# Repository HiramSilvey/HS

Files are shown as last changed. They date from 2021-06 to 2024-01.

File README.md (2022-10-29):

# HS

A highly customizable game controller with a fully analog arcade-style joystick.

To see it in action, check out this [demo](https://www.youtube.com/watch?v=5yk12DYtFRA)!

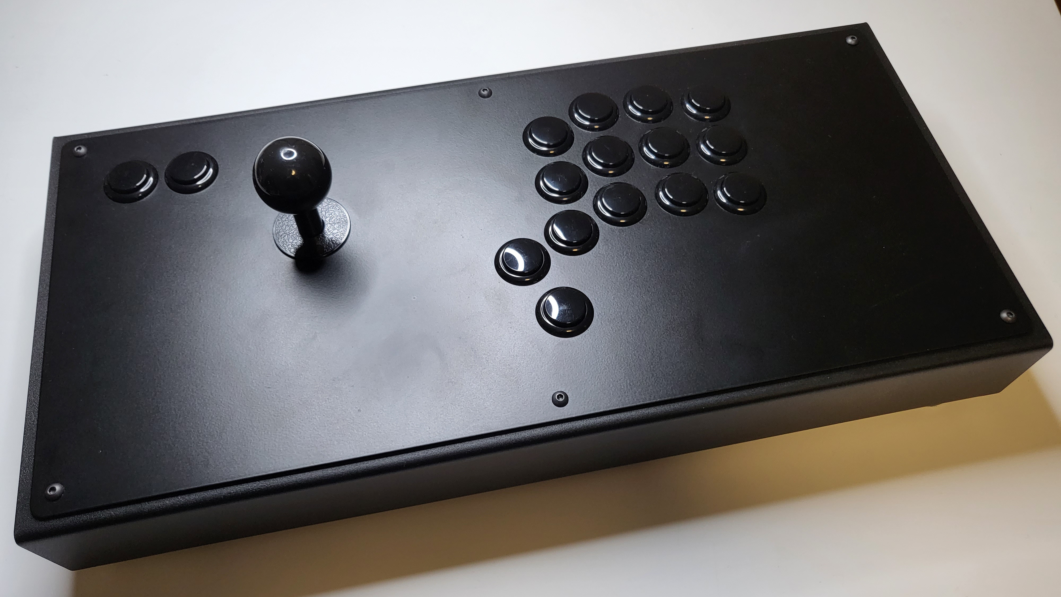
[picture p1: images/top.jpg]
HS-top-side

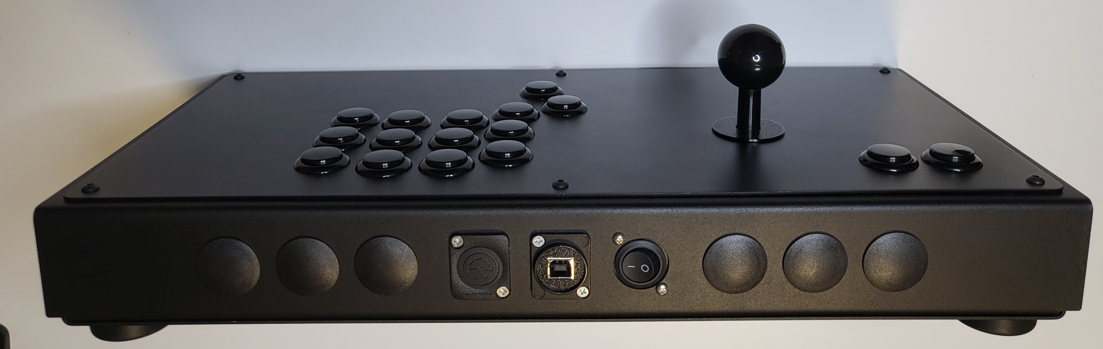
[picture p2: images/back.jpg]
HS-back-side


## Key features
* Fully analog joystick
* Works on PC and Switch, with more platforms planned
* Supports up to 12 custom button layout profiles per platform
* In-depth joystick calibration software to ensure maximum analog precision

## Profile features
* All buttons are remappable
* Buttons can be mapped to either digital or analog outputs
* Supports an optional second button layout, which becomes active while the MOD button is held down
* Supports digital joystick emulation with a custom activation threshold

## Specs
* 14", 16", or 18" standard AllFightSticks case
* 11-14 right-hand buttons, depending on the panel style chosen
* 2 left-hand buttons (recommended), either on the panel top or the back
* 1 on/off rocker switch, to specify platform (PC or Switch)
* 1 USB-C 2.0 port
* PJRC Teensy 4.0 microcontroller
* Contactless joystick via the Infineon TLV493D-A1B6 3D hall effect sensor

## TO DO
1. Write up and publish build guide
2. Rewrite the configurator frontend to support Windows & MacOS (currently Linux only)
3. Support native GameCube output

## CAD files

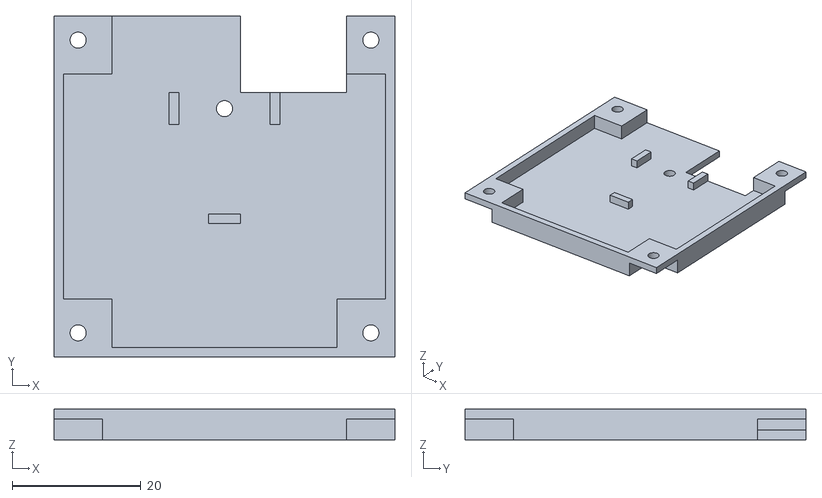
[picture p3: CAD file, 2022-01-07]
hardware/joystick/out/sensor_harness_01_spacing.stl
53.0 x 53.0 x 4.75

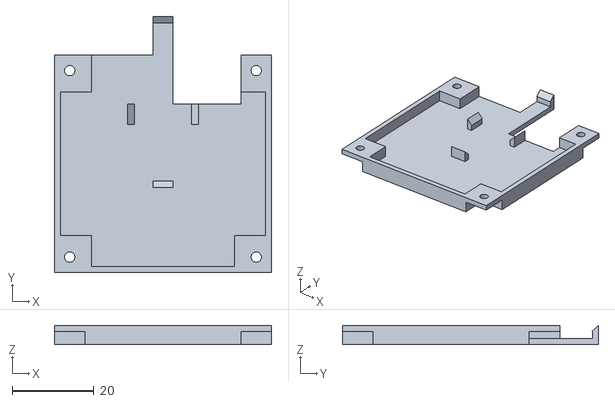
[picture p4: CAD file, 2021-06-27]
hardware/joystick/out/sensor_harness_01_spacing_01_lip.stl
53.0 x 62.5 x 4.75

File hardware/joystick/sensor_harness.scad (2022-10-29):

// All units are in mm.

min_thickness=1.5;
depth=min_thickness;
m3_dia=2.5;

width=53;
length=width;
edge_to_hole=3.75;
inner_offset=edge_to_hole*2;
inner_width=width-inner_offset*2;
inner_depth=4.75;

cutout_depth=inner_depth-min_thickness;
cutout_depth_offset=depth-cutout_depth;

board_spacing=0.1;  // Calibrated for the Prusa i3 FDM printer.
board_width=14+board_spacing;
board_height=38.5+board_spacing;
board_width_offset=(width-board_width)/2;
board_height_edge_to_sensor_center=4.35+(board_spacing/2);
board_height_offset=(width/2)-board_height_edge_to_sensor_center;
board_height_edge_to_hole_center=16.1+(board_spacing/2);
board_hole_offset=board_height_offset+board_height_edge_to_hole_center;
rail_length=6;
notch_width=(board_width-rail_length)/2;

module hole(x, y, d, dia) {
     translate([x, y, d]) cylinder(h=4.75, d=dia, center=false, $fn=100);
}

module core() {
     // Outer platform
     difference () {
	  cube([width, length, depth]);
	  hole(edge_to_hole, edge_to_hole, 0, m3_dia);
	  hole(width-edge_to_hole, edge_to_hole, 0, m3_dia);
	  hole(edge_to_hole, width-edge_to_hole, 0, m3_dia);
	  hole(width-edge_to_hole, width-edge_to_hole, 0, m3_dia);
     }
     // Solid inner platform
     translate([inner_offset, 0, depth-inner_depth])
	  cube([inner_width, width, inner_depth]);
     translate([0, inner_offset, depth-inner_depth])
	  cube([width, inner_width, inner_depth]);
}

module board() {
    // Header cutout
    translate([width/2+rail_length/2, board_hole_offset+rail_length/2,
	      depth-inner_depth]) cube([width/2-rail_length/2-edge_to_hole*2,
				       width-board_hole_offset+rail_length/2,
				       inner_depth]);
    // Board cutout
    translate([board_width_offset, board_height_offset, cutout_depth_offset])
	 cube([board_width, board_height, inner_depth]);
    // Board notches cutout
    translate([board_width_offset, board_height_offset-min_thickness, cutout_depth_offset])
	 cube([notch_width, min_thickness, inner_depth]);
    translate([board_width_offset+board_width-notch_width, board_height_offset-min_thickness, cutout_depth_offset])
	 cube([notch_width, min_thickness, inner_depth]);
}

module platform_extension() {
    translate([width/2-board_width/2-min_thickness, width, depth-inner_depth]) cube([board_width/2+rail_length/2+min_thickness, board_height_offset+board_height-width+min_thickness, min_thickness]);
    translate([width/2-rail_length/2, board_height_offset+board_height,
    cutout_depth_offset]) cube([rail_length, min_thickness, cutout_depth]);
    translate([width/2-board_width/2-min_thickness, width, cutout_depth_offset]) cube([min_thickness, board_height_offset+board_height-width+min_thickness, cutout_depth]);
}

difference () {
    core();
    board();
}

platform_extension();

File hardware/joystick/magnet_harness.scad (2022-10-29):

// All units are in mm.

spacing=0.1;  // Calibrated for the Prusa i3 FDM printer.

min_thickness=1;
shaft_height=2;
shaft_dia=6.85+spacing;
magnet_height=3.175;  // 0.125"
magnet_dia=19.05+spacing;  // 0.750"
outer_dia=magnet_dia+(2*min_thickness);

$fn=360;

difference() {
  body();
  magnet();
  shaft();
}

module body() {
  cylinder(h=magnet_height+shaft_height, d1=outer_dia, d2=outer_dia);
}

module magnet() {
  translate([0,0,0]) {
    cylinder(h=magnet_height, d1=magnet_dia, d2=magnet_dia);
  }
}

module shaft() {
  translate([0,0,magnet_height]) {
    cylinder(h=shaft_height, d1=shaft_dia, d2=shaft_dia);
  }
}

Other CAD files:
hardware/joystick/src/magnet_harness.scad

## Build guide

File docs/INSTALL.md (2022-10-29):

# Required tools
1. Soldering iron + solder
2. 22 gauge wire strippers
3. Standard phillips head screwdrivers
4. 3/32" allen wrench

# Parts
| Link | Quantity  |
|:---|:---|
| [Teensy 4.0](https://www.digikey.com/en/products/detail/sparkfun-electronics/DEV-15583/10384551) | 1 |
| [TLV493D-A1B6 magnetic sensor board](https://www.digikey.com/en/products/detail/infineon-technologies/S2GO3DSENSETLV493DTOBO1/9808564) | 1 |
| [Magnet](https://www.digikey.com/en/products/detail/radial-magnets-inc/8013/555325) | 1 |
| [1x5 male pin header](https://www.digikey.com/en/products/detail/sullins-connector-solutions/PBC05SAAN/859626) | 1 |
| [1x14 male pin header](https://www.digikey.com/en/products/detail/sullins-connector-solutions/PBC14SAAN/859635) | 2 |
| [1x3 screw terminal header](https://www.digikey.com/en/products/detail/on-shore-technology-inc/OSTVN03A150/1588863) | 1 |
| [1x4 screw terminal header](https://www.digikey.com/en/products/detail/on-shore-technology-inc/OSTVN04A150/1588864) | 3 |
| [1x10 screw terminal header](https://www.digikey.com/en/products/detail/on-shore-technology-inc/OSTVN10A150/1588870) | 1 |
| [1x12 screw terminal header](https://www.digikey.com/en/products/detail/on-shore-technology-inc/OSTVN12A150/1588872) | 2 |
| [40mm brass spacer](https://www.digikey.com/en/products/detail/w%C3%BCrth-elektronik/970400324/9488593) | 4 |
| [M3 machine screw](https://www.digikey.com/en/products/detail/keystone-electronics/9191-3/4499484) | 4 |
| [Teensy breakout board](https://www.tindie.com/products/raster/teensy-breakout-board-v16/) | 1 |
| [Sanwa JLF-TP-8YT joystick](https://focusattack.com/sanwa-jlf-tp-8yt-joystick/) | 1 |
| [Seimitsu black LB-35 balltop](https://focusattack.com/seimitsu-solid-color-black-lb-35-balltop/) | 1 |
| [Short Sanwa JLF joystick shaft](https://focusattack.com/short-sanwa-jlf-joystick-shaft/) | 1 |
| [Sanwa GT-8X square restrictor gate](https://focusattack.com/sanwa-gt-8x-square-restrictor-gate/) | 1 |
| [GTN-R square mod type I restrictor gate insert](https://focusattack.com/gtn-r-square-mod-type-i-restrictor-gate-insert/) | 1 |
| [Sanwa JLF blue spring (1.5, 1.5 tension load)](https://focusattack.com/sanwa-jlf-blue-spring-1-5-1-5-tension-load/) | 1 |
| [Sanwa JLF P-R actuator](https://focusattack.com/sanwa-jlf-p-r-actuator/) | 1 |
| [Solo Sanwa JLF dustwasher](https://focusattack.com/solo-sanwa-jlf-dustwasher-fits-sanwa-jlf-without-shaft-cover-set-of-2/) | 1 |
| [Sanwa JLF-SS-kit](https://focusattack.com/sanwa-jlf-ss-kit-set-of-4/) | 1 |
| [USB C jack to USB A jack round panel mount adapter](https://focusattack.com/usb-c-jack-to-usb-a-jack-round-panel-mount-adapter/) | 1 |
| [16pc 22 AWG wire with .110 quick disconnect](https://focusattack.com/16pc-22-awg-wire-with-110-quick-disconnect/) | 1 |
| [16pc 22 AWG wire with .187 quick disconnect](https://focusattack.com/16pc-22-awg-wire-with-187-quick-disconnect/) | 1 |
| [30 connection 22 AWG .110" ground daisy chain wire](https://focusattack.com/30-connection-22-awg-110-ground-daisy-chain-wire/) | 1 |
| [3mm hole low profile adhesize PCB feet (set of 4)](https://focusattack.com/3mm-hole-low-profile-adhesive-pcb-feet-set-of-4/) | 1 |
| [24mm Pushbutton](https://focusattack.com/controls/pushbutton/by-hole-diameter/24mm/) | 12/16[^1] |
| [Neutrik DBA-BL blank plate](https://focusattack.com/neutrik-dba-bl-blank-plate/) | 1 |
| [Hole plug](https://allfightsticks.com/products/screw-in-hole-plugs) | 4-6[^2] |
| AllFightSticks enclosure ([14"](https://allfightsticks.com/collections/14-enclosures/products/14-semi-modular-body), [16"](https://allfightsticks.com/collections/16-enclosures/products/16-bodies), [18"](https://allfightsticks.com/collections/18-enclosures/products/18-standard-bodies))[^3] | 1 |
| [10 foot male A-C USB 2.0 cable](https://www.amazon.com/gp/product/B01D3095RW) | 1 |
| [Right angle micro USB to USB 2.0 cable](https://www.amazon.com/gp/product/B01LYYT3N3) | 1 |
| [Laser cut panel](/hardware/panel/README.md) | 1 |
| [3D printed joystick harnesses](/hardware/joystick/README.md) | 1 ea. |

[^1]: 12 pushbuttons if using the CORE panel layout; 16 pushbuttons if using the FULL panel layout.
[^2]: 6 hole plugs minus the number of extra buttons on the panel.
[^3]: Include a joystick mounting plate. Order without a button panel.

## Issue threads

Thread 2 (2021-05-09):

Clean up joystick calibration code and merge it into the main binary

HiramSilvey, 2021-05-09:

HiramSilvey, 2021-07-11:
Refactor calibration code to use full circle motions (easier to do) where only the largest and smallest values are kept (rather than averaging values). Then, do some manual testing to determine how close to those absolute minimums and maximums standard joystick movements get. From there, determine a threshold (e.g. 95%) which should be applied to the minimum and maximum values to obtain tighter bounds which allow all values of the joystick to realistically be reached in standard use.

Additionally add supporting code to the configurator client which sends and receives calibration serial data. This will enable users to move completely off of the Arduino IDE except for code updates (which will be tackled separately in the future).

Closed 2021-07-17.

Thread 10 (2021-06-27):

Add support for outputting to Nintendo Gamecube

HiramSilvey, 2021-06-27:
Arduino support for this is here: https://github.com/NicoHood/Nintendo
In order to support Teensy 4.0+, the protocol needs to be re-written since the NicoHood library is written specifically for the AVR cpu architecture. Since the Teensy is so much faster than the Arduino, though, it may be possible to implement the protocol using bit-banging rather than inserting the exact number of NOP instructions.

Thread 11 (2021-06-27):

Add support for outputting to N64

HiramSilvey, 2021-06-27:
Arduino support for this is here: https://github.com/NicoHood/Nintendo
In order to support Teensy 4.0+, the protocol needs to be re-written since the NicoHood library is written specifically for the AVR cpu architecture. Since the Teensy is so much faster than the Arduino, though, it may be possible to implement the protocol using bit-banging rather than inserting the exact number of NOP instructions.

HiramSilvey, 2021-06-30:
Investigate forking the controller implementation in https://github.com/Ryzee119/usb64.

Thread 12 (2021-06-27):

Add detailed documentation

HiramSilvey, 2021-06-27:
Document:
* The purpose of the controller
* The design principles of the controller
* How to build
** How to get the panel laser cut
* How to run the configurator
* How to run the calibration code
* How to use the controller

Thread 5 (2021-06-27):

Widen panel button holes to better fit 24mm Sanwa buttons

HiramSilvey, 2021-06-27:
The buttons do currently fit in the holes, but it's snug enough that inserting and removing them is difficult and can strip some of their side wall plastic off.

HiramSilvey, 2021-07-25:
This might be OK. Holes are 24.3mm currently, which is the desired width according to measurements I've made on commercial panels. I will re-open this if it feels too tight in a second build.

Closed 2021-07-25.

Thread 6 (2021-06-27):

Investigate Seimitsu LS40 joystick as a possible alternative

HiramSilvey, 2021-06-27:
Some fightstick users prefer the feel and tension options of the Seimitsu LS40 over the Sanwa JLF. Investigate what it would take to support this joystick and experiment with it, in case users are interested.

HiramSilvey, 2022-03-05:
Ordered LS-32 and LS-40 for experimentation.

HiramSilvey, 2022-03-26:
"ls-40" branch contains changes I've been playing around with.

Yesterday I got a working ls-40 prototype.
Pros:
1. Extremely stable sensor readings. No jitter whatsoever.
2. Shorter throw.
3. Less wiggling in neutral position.
4. Less snapback when releasing the joystick to neutral position.
Cons:
1. Rotating the joystick still affects the sensor readings more than I'd like. This doesn't appear to be worse than the JLF, though. To combat this, I'm going to try using the Seimitsu Nobi lever next, which uses the same bottom plates as the ls-40. The Nobi is unique because its joystick shaft cannot rotate.

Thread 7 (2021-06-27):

Experiment moving lowest thumb button to reduce strain

HiramSilvey, 2021-06-27:
Currently the lowest thumb button is pretty far from the highest thumb button. This introduces a fairly significant finger travel distance when moving from thumb top to thumb bottom. That affects both the speed at which the button can be pressed as well as the strain introduced on the thumb.

Closed 2021-07-25.

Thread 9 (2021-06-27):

Add support for outputting to Nintendo Switch

HiramSilvey, 2021-06-27:

HiramSilvey, 2021-06-28:
Try using https://github.com/gdsports/NSGadget_Teensy/blob/master/hardware/teensy/avr/cores/teensy4/usb_nsgamepad.h

HiramSilvey, 2021-06-29:
Example: https://github.com/gdsports/NSGadget_Teensy/blob/master/examples/NSGamepad/NSGamepad.ino

HiramSilvey, 2021-07-06:
See https://github.com/HiramSilvey/HS/commit/f24bbb9ad9f6cdd905fb99b6a781aad39aac6bb8 and previous few commits for details on how this was done.

Closed 2021-07-06.

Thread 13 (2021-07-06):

Dynamically set USB type based on hardware switch

HiramSilvey, 2021-07-06:
See https://forum.pjrc.com/threads/67639-Is-it-possible-to-have-a-dynamic-USB-VID-PID for more information.

Closed 2021-07-11.

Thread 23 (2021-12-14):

Verify profile creation and flashing works on Windows.

HiramSilvey, 2021-12-14:

HiramSilvey, 2022-02-26:
Communication with the controller works as expected, but the UI freezes and is rendered unusable. This might be a bug in druid, or may be an issue with my implementation.

I'm considering rewriting the UI in something like electron and calling into my rust functions from it for controller communication. Is that feasible? More research to be done.

HiramSilvey, 2022-02-27:
After some research, rewriting the UI using electron, node.js, and neon (https://github.com/neon-bindings/neon) seems pretty straightforward and should be very reliable across mac, linux, and windows.

I will move forward with this approach and convert the current druid implementation. This also seems like a good time to revamp the UI to include button layouts as well, so I'll need to do some UI mocking before really diving in.

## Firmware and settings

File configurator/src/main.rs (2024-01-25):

// Copyright 2024 Hiram Silvey

use anyhow::{anyhow, Result};
use configurator::encoder;
use configurator::profiles;
use crossbeam_channel::{unbounded, Receiver, Sender};
use druid::kurbo::{Circle, Line};
use druid::piet::StrokeStyle;
use druid::widget::prelude::*;
use druid::widget::{Button, Flex, Label, Painter};
use druid::{
    theme, AppLauncher, Color, Data, ExtEventSink, Lens, PlatformError, Point, Rect, RenderContext,
    Selector, Target, Widget, WidgetExt, WindowDesc,
};
use serialport::SerialPort;
use std::path::Path;
use std::thread;
use std::time::{Duration, Instant};

const MAX_EEPROM_BYTES: usize = 1064;
const JOYSTICK_CURSOR_RADIUS: f64 = 3.;
const JOYSTICK_BOX_LENGTH: f64 = 400.;
const SET_CURSOR: Selector<Point> = Selector::new("hs.set-cursor");
const SET_DEFAULT_BOUNDS: Selector<Bounds> = Selector::new("hs.set-default-bounds");

#[derive(Clone, Copy)]
enum Command {
    FetchStoredBounds,
    FetchJoystickCoords,
    CalibrateJoystick,
    SaveCalibration,
    StoreProfiles,
}

#[derive(Clone, Copy, Data, Lens)]
struct Bounds {
    center: Point,
    range: f64,
    angle_ticks: i16,
}

impl Bounds {
    pub fn new() -> Bounds {
        Bounds {
            center: Point::new(0.0, 0.0),
            range: 0.0,
            angle_ticks: 0,
        }
    }

    pub fn from_parts(center_x: f64, center_y: f64, range: f64, angle_ticks: i16) -> Bounds {
        Bounds {
            center: Point::new(center_x, center_y),
            range: range,
            angle_ticks: angle_ticks,
        }
    }

    fn get_x_min(&self) -> f64 {
        self.center.x - self.range
    }

    fn get_x_max(&self) -> f64 {
        self.center.x + self.range
    }

    fn get_y_min(&self) -> f64 {
        self.center.y + self.range
    }

    fn get_y_max(&self) -> f64 {
        self.center.y - self.range
    }
}

#[derive(Clone, Copy)]
enum Direction {
    Up,
    Down,
    Left,
    Right,
    In,
    Out,
    AngleInc,
    AngleDec,
}

#[derive(Clone, Data, Lens)]
struct JoystickState {
    cursor: Point,
    default_bounds: Bounds,
    custom_bounds: Bounds,
    digital_threshold: f64,
}

impl JoystickState {
    pub fn new() -> JoystickState {
        JoystickState {
            cursor: Point::new(0.0, 0.0),
            default_bounds: Bounds::new(),
            custom_bounds: Bounds::new(),
            digital_threshold: 0.0,
        }
    }

    fn set_cursor(&mut self, point: &Point) {
        self.cursor = *point;
    }

    fn set_bounds(&mut self, bounds: &Bounds) {
        self.default_bounds = *bounds;
        self.custom_bounds = *bounds;

        println!(
            "Set bounds to x={}, y={}, range={}, angle_ticks={}",
            self.default_bounds.center.x,
            self.default_bounds.center.y,
            self.default_bounds.range,
            self.default_bounds.angle_ticks
        );
    }

    fn shift_bounds(&mut self, direction: Direction) {
        let tick = self.default_bounds.range / 1000.0;

        match direction {
            Direction::Up => self.custom_bounds.center.y += tick,
            Direction::Down => self.custom_bounds.center.y -= tick,
            Direction::Left => self.custom_bounds.center.x -= tick,
            Direction::Right => self.custom_bounds.center.x += tick,
            Direction::In => self.custom_bounds.range -= tick,
            Direction::Out => self.custom_bounds.range += tick,
            Direction::AngleInc => self.custom_bounds.angle_ticks += 1,
            Direction::AngleDec => self.custom_bounds.angle_ticks -= 1,
        }
    }
}

fn get_button_painter() -> Painter<JoystickState> {
    Painter::new(|ctx, _, env| {
        let bounds = ctx.size().to_rect();

        ctx.fill(bounds, &env.get(theme::PRIMARY_DARK));

        if ctx.is_hot() {
            ctx.stroke(bounds.inset(-0.5), &Color::WHITE, 1.0);
        }

        if ctx.is_active() {
            ctx.fill(bounds, &env.get(theme::PRIMARY_LIGHT));
        }
    })
}

fn edit_bounds_button(direction: Direction) -> impl Widget<JoystickState> {
    let symbol = match direction {
        Direction::Up => '↑',
        Direction::Down => '↓',
        Direction::Left => '←',
        Direction::Right => '→',
        Direction::In => '-',
        Direction::Out => '+',
        Direction::AngleInc => '⟲',
        Direction::AngleDec => '⟳',
    };

    Label::new(format!("{}", symbol))
        .with_text_size(14.0)
        .center()
        .background(get_button_painter())
        .expand()
        .on_click(move |_ctx, data: &mut JoystickState, _env| data.shift_bounds(direction))
}

fn edit_threshold_button(direction: Direction) -> impl Widget<JoystickState> {
    let (symbol, val) = match direction {
        Direction::In => ("D-", -1.0),
        Direction::Out => ("D+", 1.0),
        _ => ("", 0.0),
    };

    Label::new(format!("{}", symbol))
        .with_text_size(14.0)
        .center()
        .background(get_button_painter())
        .expand()
        .on_click(move |_ctx, data: &mut JoystickState, _env| data.digital_threshold += val)
}

fn map(x: f64, in_min: f64, in_max: f64, out_min: f64, out_max: f64) -> f64 {
    (x - in_min) * (out_max - out_min) / (in_max - in_min) + out_min
}

fn relative_rotated_point(x: f64, y: f64, origin_x: f64, origin_y: f64, angle_ticks: i16) -> Point {
    let relative_x = x - origin_x;
    let relative_y = y - origin_y;

    // It takes 1000 angle ticks to reach PI/2, or 90 degrees.
    let angle = std::f64::consts::PI * angle_ticks as f64 / 2000.;

    let mut p = Point::new(
        (relative_x * angle.cos()) + (relative_y * angle.sin()),
        (-relative_x * angle.sin()) + (relative_y * angle.cos()),
    );
    p.x += origin_x;
    p.y += origin_y;
    p
}

impl Widget<JoystickState> for JoystickState {
    fn event(&mut self, _ctx: &mut EventCtx, event: &Event, data: &mut JoystickState, _env: &Env) {
        match event {
            Event::Command(cmd) if cmd.is(SET_CURSOR) => {
                let point = cmd.get_unchecked(SET_CURSOR).clone();
                data.set_cursor(&point);
            }
            Event::Command(cmd) if cmd.is(SET_DEFAULT_BOUNDS) => {
                let bounds = cmd.get_unchecked(SET_DEFAULT_BOUNDS).clone();
                data.set_bounds(&bounds);
            }
            _ => (),
        }
    }

    fn lifecycle(
        &mut self,
        _ctx: &mut LifeCycleCtx,
        _event: &LifeCycle,
        _data: &JoystickState,
        _env: &Env,
    ) {
    }

    fn update(
        &mut self,
        ctx: &mut UpdateCtx,
        _old_data: &JoystickState,
        _data: &JoystickState,
        _env: &Env,
    ) {
        ctx.request_paint();
    }

    fn layout(
        &mut self,
        _layout_ctx: &mut LayoutCtx,
        bc: &BoxConstraints,
        _data: &JoystickState,
        _env: &Env,
    ) -> Size {
        if bc.is_width_bounded() | bc.is_height_bounded() {
            let size = Size::new(JOYSTICK_BOX_LENGTH, JOYSTICK_BOX_LENGTH);
            bc.constrain(size)
        } else {
            bc.max()
        }
    }

    fn paint(&mut self, ctx: &mut PaintCtx, data: &JoystickState, env: &Env) {
        // Absolute bounds.
        let size = ctx.size();
        let rect = size.to_rect();
        ctx.fill(rect, &env.get(theme::BACKGROUND_DARK));
        ctx.stroke(rect, &env.get(theme::BACKGROUND_LIGHT), 1.0);

        let default_range = (size.width * 0.875) / 2.0;
        let default_x_min = rect.center().x - default_range;
        let default_x_max = rect.center().x + default_range;
        let default_y_min = rect.center().y - default_range;
        let default_y_max = rect.center().y + default_range;

        // Default bounds.
        let default_bounds = Rect::from_points(
            Point::new(default_x_min, default_y_min),
            Point::new(default_x_max, default_y_max),
        );
        ctx.stroke(default_bounds, &env.get(theme::BACKGROUND_LIGHT), 1.0);

        // Mutable bounds.
        let mutable_x_min = map(
            data.custom_bounds.get_x_min(),
            data.default_bounds.get_x_min(),
            data.default_bounds.get_x_max(),
            default_x_min,
            default_x_max,
        );
        let mutable_x_max = map(
            data.custom_bounds.get_x_max(),
            data.default_bounds.get_x_min(),
            data.default_bounds.get_x_max(),
            default_x_min,
            default_x_max,
        );
        let mutable_x_center = mutable_x_min + (mutable_x_max - mutable_x_min) / 2.0;
        let mutable_y_min = map(
            data.custom_bounds.get_y_min(),
            data.default_bounds.get_y_min(),
            data.default_bounds.get_y_max(),
            default_y_min,
            default_y_max,
        );
        let mutable_y_max = map(
            data.custom_bounds.get_y_max(),
            data.default_bounds.get_y_min(),
            data.default_bounds.get_y_max(),
            default_y_min,
            default_y_max,
        );
        let mutable_y_center = mutable_y_min + (mutable_y_max - mutable_y_min) / 2.0;
        let mutable_center = Point::new(mutable_x_center, mutable_y_center);

        let mutable_top_left = relative_rotated_point(
            mutable_x_min,
            mutable_y_min,
            mutable_x_center,
            mutable_y_center,
            data.custom_bounds.angle_ticks,
        );
        let mutable_top_right = relative_rotated_point(
            mutable_x_max,
            mutable_y_min,
            mutable_x_center,
            mutable_y_center,
            data.custom_bounds.angle_ticks,
        );
        let mutable_bottom_left = relative_rotated_point(
            mutable_x_min,
            mutable_y_max,
            mutable_x_center,
            mutable_y_center,
            data.custom_bounds.angle_ticks,
        );
        let mutable_bottom_right = relative_rotated_point(
            mutable_x_max,
            mutable_y_max,
            mutable_x_center,
            mutable_y_center,
            data.custom_bounds.angle_ticks,
        );
        let mutable_center_left = relative_rotated_point(
            mutable_x_min,
            mutable_y_center,
            mutable_x_center,
            mutable_y_center,
            data.custom_bounds.angle_ticks,
        );
        let mutable_center_right = relative_rotated_point(
            mutable_x_max,
            mutable_y_center,
            mutable_x_center,
            mutable_y_center,
            data.custom_bounds.angle_ticks,
        );
        let mutable_center_top = relative_rotated_point(
            mutable_x_center,
            mutable_y_min,
            mutable_x_center,
            mutable_y_center,
            data.custom_bounds.angle_ticks,
        );
        let mutable_center_bottom = relative_rotated_point(
            mutable_x_center,
            mutable_y_max,
            mutable_x_center,
            mutable_y_center,
            data.custom_bounds.angle_ticks,
        );

        // Mutable bounds' box.
        ctx.stroke(
            Line::new(mutable_top_left, mutable_bottom_left),
            &env.get(theme::PRIMARY_LIGHT),
            1.0,
        );
        ctx.stroke(
            Line::new(mutable_top_left, mutable_top_right),
            &env.get(theme::PRIMARY_LIGHT),
            1.0,
        );
        ctx.stroke(
            Line::new(mutable_bottom_right, mutable_top_right),
            &env.get(theme::PRIMARY_LIGHT),
            1.0,
        );
        ctx.stroke(
            Line::new(mutable_bottom_right, mutable_bottom_left),
            &env.get(theme::PRIMARY_LIGHT),
            1.0,
        );

        // Mutable bounds' guidelines.
        let stroke_style = StrokeStyle::new().dash_pattern(&[1.0, 4.0]);
        ctx.stroke_styled(
            Line::new(mutable_center, mutable_center_left),
            &env.get(theme::PRIMARY_DARK),
            1.0,
            &stroke_style,
        );
        ctx.stroke_styled(
            Line::new(mutable_center, mutable_top_left),
            &env.get(theme::PRIMARY_DARK),
            1.0,
            &stroke_style,
        );
        ctx.stroke_styled(
            Line::new(mutable_center, mutable_center_top),
            &env.get(theme::PRIMARY_DARK),
            1.0,
            &stroke_style,
        );
        ctx.stroke_styled(
            Line::new(mutable_center, mutable_top_right),
            &env.get(theme::PRIMARY_DARK),
            1.0,
            &stroke_style,
        );
        ctx.stroke_styled(
            Line::new(mutable_center, mutable_center_right),
            &env.get(theme::PRIMARY_DARK),
            1.0,
            &stroke_style,
        );
        ctx.stroke_styled(
            Line::new(mutable_center, mutable_bottom_right),
            &env.get(theme::PRIMARY_DARK),
            1.0,
            &stroke_style,
        );
        ctx.stroke_styled(
            Line::new(mutable_center, mutable_center_bottom),
            &env.get(theme::PRIMARY_DARK),
            1.0,
            &stroke_style,
        );
        ctx.stroke_styled(
            Line::new(mutable_center, mutable_bottom_left),
            &env.get(theme::PRIMARY_DARK),
            1.0,
            &stroke_style,
        );

        // Mutable digital threshold.
        let threshold_x_range =
            (mutable_x_max - mutable_x_center) * (data.digital_threshold / 100.0);
        let threshold_y_range =
            (mutable_y_max - mutable_y_center) * (data.digital_threshold / 100.0);
        let threshold = Rect::from_points(
            Point::new(
                mutable_x_center - threshold_x_range,
                mutable_y_center - threshold_y_range,
            ),
            Point::new(
                mutable_x_center + threshold_x_range,
                mutable_y_center + threshold_y_range,
            ),
        );
        ctx.stroke(threshold, &env.get(theme::PRIMARY_LIGHT), 1.0);

        // Cursor.
        let cursor_x = map(
            data.cursor.x,
            data.default_bounds.get_x_min(),
            data.default_bounds.get_x_max(),
            default_x_min,
            default_x_max,
        );
        let cursor_y = map(
            data.cursor.y,
            data.default_bounds.get_y_min(),
            data.default_bounds.get_y_max(),
            default_y_min,
            default_y_max,
        );
        let cursor_color = env.get(theme::CURSOR_COLOR);
        ctx.paint_with_z_index(1, move |ctx| {
            let cursor = Circle::new(Point::new(cursor_x, cursor_y), JOYSTICK_CURSOR_RADIUS);
            ctx.stroke(cursor, &cursor_color, 2.0);
        });
    }
}

fn connect() -> Result<Box<dyn SerialPort>> {
    let port = "/dev/ttyACM0";
    match serialport::new(port, 9600)
        .timeout(Duration::from_millis(10))
        .open()
    {
        Ok(x) => Ok(x),
        Err(e) => Err(anyhow!(
            "Unable to connect to HS via serial port {}: {}",
            port,
            e
        )),
    }
}

fn wait_for_data(hs: &mut Box<dyn SerialPort>, buf: &mut Vec<u8>) -> Result<()> {
    let now = Instant::now();
    let timeout = Duration::new(70, 0);
    let mut status = hs.read_exact(buf);
    while status.is_err() && now.elapsed() < timeout {
        status = hs.read_exact(buf);
    }
    if status.is_err() {
        return Err(anyhow!(
            "Failed waiting for data from HS: {}",
            status.unwrap_err()
        ));
    }
    Ok(())
}

fn wait_for_ack(hs: &mut Box<dyn SerialPort>) -> Result<()> {
    let mut buf = vec![0u8; 1];
    wait_for_data(hs, &mut buf)?;
    if buf[0] != 0 {
        return Err(anyhow!("Failed to receive ACK. Wanted 0, got {}.", buf[0]));
    }
    Ok(())
}

fn bytes_to_short(bytes: &Vec<u8>) -> Result<i16> {
    if bytes.len() != 2 {
        return Err(anyhow!(
            "Failed converting bytes to short. Expected 2 bytes, found {} bytes.",
            bytes.len()
        ));
    }
    Ok(((bytes[0] as i16) << 8) | bytes[1] as i16)
}

fn bytes_to_float(bytes: &Vec<u8>) -> Result<f64> {
    if bytes.len() != 4 {
        return Err(anyhow!(
            "Failed converting bytes to float. Expected 4 bytes, found {} bytes.",
            bytes.len()
        ));
    }
    Ok((((bytes[0] as i32) << 24)
        | ((bytes[1] as i32) << 16)
        | ((bytes[2] as i32) << 8)
        | bytes[3] as i32) as f64)
}

fn short_to_bytes(data: i16) -> Vec<u8> {
    vec![(data >> 8 & 0xFF) as u8, (data & 0xFF) as u8]
}

fn float_to_bytes(data: f64) -> Vec<u8> {
    let i32_data = data as i32;
    vec![
        (i32_data >> 24) as u8,
        (i32_data >> 16 & 0xFF) as u8,
        (i32_data >> 8 & 0xFF) as u8,
        (i32_data & 0xFF) as u8,
    ]
}

fn fetch_stored_bounds(hs: &mut Box<dyn SerialPort>, event_sink: &ExtEventSink) -> Result<()> {
    let mut center_x = vec![0u8; 4];
    let mut center_y = vec![0u8; 4];
    let mut range = vec![0u8; 4];
    let mut angle_ticks = vec![0u8; 2];
    wait_for_data(hs, &mut center_x)?;
    wait_for_data(hs, &mut center_y)?;
    wait_for_data(hs, &mut range)?;
    wait_for_data(hs, &mut angle_ticks)?;

    event_sink.submit_command(
        SET_DEFAULT_BOUNDS,
        Bounds::from_parts(
            bytes_to_float(&center_x)?,
            bytes_to_float(&center_y)?,
            bytes_to_float(&range)?,
            bytes_to_short(&angle_ticks)?,
        ),
        Target::Auto,
    )?;

    Ok(())
}

fn fetch_joystick_coords(hs: &mut Box<dyn SerialPort>, event_sink: &ExtEventSink) -> Result<()> {
    let mut x = vec![0u8; 4];
    let mut y = vec![0u8; 4];
    wait_for_data(hs, &mut x)?;
    wait_for_data(hs, &mut y)?;

    event_sink.submit_command(
        SET_CURSOR,
        Point::new(bytes_to_float(&x)?, bytes_to_float(&y)?),
        Target::Auto,
    )?;

    Ok(())
}

fn calibrate_joystick(hs: &mut Box<dyn SerialPort>, sender: &Sender<f64>) -> Result<()> {
    let mut center_x_buf = vec![0u8; 4];
    let mut center_y_buf = vec![0u8; 4];
    let mut range_buf = vec![0u8; 4];
    wait_for_data(hs, &mut center_x_buf)?;
    wait_for_data(hs, &mut center_y_buf)?;
    wait_for_data(hs, &mut range_buf)?;

    sender.send(bytes_to_float(&center_x_buf)?)?;
    sender.send(bytes_to_float(&center_y_buf)?)?;
    sender.send(bytes_to_float(&range_buf)?)?;

    Ok(())
}

fn save_calibration(
    hs: &mut Box<dyn SerialPort>,
    sender: &Sender<f64>,
    receiver: &Receiver<f64>,
) -> Result<()> {
    let center_x = receiver.recv()?;
    let center_y = receiver.recv()?;
    let range = receiver.recv()?;
    let angle_ticks = receiver.recv()?;

    hs.write_all(&float_to_bytes(center_x))?;
    hs.write_all(&float_to_bytes(center_y))?;
    hs.write_all(&float_to_bytes(range))?;
    hs.write_all(&short_to_bytes(angle_ticks as i16))?;

    wait_for_ack(hs)?;

    sender.send(0.0)?;
    Ok(())
}

fn store_profiles(hs: &mut Box<dyn SerialPort>, sender: &Sender<f64>) -> Result<()> {
    let profiles = match profiles::load_all(&Path::new("../profiles")) {
        Ok(x) => x,
        Err(e) => return Err(anyhow!("Unable to load profiles: {}", e)),
    };

    // Print as useful debug information.
    for profile in &profiles {
        println!("{}", profile);
    }

    let encoded = match encoder::encode(&profiles) {
        Ok(x) => x,
        Err(e) => return Err(anyhow!("Unable to encode profiles: {}", e)),
    };
    if encoded.len() > MAX_EEPROM_BYTES {
        return Err(anyhow!(
            "Encoded length of {} bytes exceeds HS maximum of {} bytes.",
            encoded.len(),
            MAX_EEPROM_BYTES,
        ));
    }

    let size = encoded.len();
    hs.write_all(&[(size >> 8) as u8, (size & 0xFF) as u8])?;
    hs.write_all(&encoded)?;
    wait_for_ack(hs)?;

    sender.send(0.0)?;
    Ok(())
}
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
pub fn main() -> Result<(), PlatformError> {
    let (cmd_sender, cmd_receiver) = unbounded();
    let (child_data_sender, parent_data_receiver) = unbounded();
    let (parent_data_sender, child_data_receiver) = unbounded();

    let launcher = AppLauncher::with_window(
        WindowDesc::new(build_ui(
            cmd_sender,
            parent_data_sender,
            parent_data_receiver,
        ))
        .title("HS Configurator")
        .window_size((JOYSTICK_BOX_LENGTH, JOYSTICK_BOX_LENGTH + 150.0))
        .with_min_size((JOYSTICK_BOX_LENGTH, JOYSTICK_BOX_LENGTH)),
    );

    let event_sink = launcher.get_external_handle();
    thread::spawn(move || -> Result<()> {
        drive(
            child_data_sender,
            child_data_receiver,
            cmd_receiver,
            event_sink,
        )
    });

    launcher.launch(JoystickState::new())?;

    Ok(())
}

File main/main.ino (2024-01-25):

// Copyright 2024 Hiram Silvey

#include <memory>

#include "configurator.h"
#include "controller.h"
#include "ns_controller.h"
#include "nspad_impl.h"
#include "pc_controller.h"
#include "pins.h"
#include "teensy_impl.h"

std::unique_ptr<hs::Controller> controller;
extern uint8_t nsgamepad_active;
extern volatile uint8_t usb_configuration;

void InitPins() {
  pinMode(hs::pins::kThumbTop, INPUT_PULLUP);
  pinMode(hs::pins::kThumbMiddle, INPUT_PULLUP);
  pinMode(hs::pins::kThumbBottom, INPUT_PULLUP);
  pinMode(hs::pins::kIndexTop, INPUT_PULLUP);
  pinMode(hs::pins::kIndexMiddle, INPUT_PULLUP);
  pinMode(hs::pins::kMiddleTop, INPUT_PULLUP);
  pinMode(hs::pins::kMiddleMiddle, INPUT_PULLUP);
  pinMode(hs::pins::kMiddleBottom, INPUT_PULLUP);
  pinMode(hs::pins::kRingTop, INPUT_PULLUP);
  pinMode(hs::pins::kRingMiddle, INPUT_PULLUP);
  pinMode(hs::pins::kRingBottom, INPUT_PULLUP);
  pinMode(hs::pins::kPinkyTop, INPUT_PULLUP);
  pinMode(hs::pins::kPinkyMiddle, INPUT_PULLUP);
  pinMode(hs::pins::kPinkyBottom, INPUT_PULLUP);
  pinMode(hs::pins::kLeftOuter, INPUT_PULLUP);
  pinMode(hs::pins::kLeftInner, INPUT_PULLUP);
  delayMicroseconds(50);  // Allow the resistors time to pull up the pins fully.
}

void setup() {
  InitPins();

  auto teensy = std::make_unique<hs::TeensyImpl>();
  if (teensy->DigitalReadLow(hs::pins::kLeftOuter)) {
    hs::configurator::Configure(std::move(teensy));
    exit(0);
  }

  while (true) {
    if (usb_configuration) {
      if (nsgamepad_active) {
	auto nspad = std::make_unique<hs::NSPadImpl>();
	controller = std::make_unique<hs::NSController>(std::move(teensy),
							std::move(nspad));
      } else {
	controller = std::make_unique<hs::PCController>(std::move(teensy));
      }
      break;
    }
    delay(50);
  }
}

void loop() { controller->Loop(); }

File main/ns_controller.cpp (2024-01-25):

// Copyright 2024 Hiram Silvey

#include "ns_controller.h"

#include <memory>

#include "hall_joystick.h"
#include "nspad.h"
#include "pins.h"
#include "profile.pb.h"
#include "teensy.h"

namespace hs {

using Layout = hs_profile_Profile_Layout;
using Layer = hs_profile_Profile_Layer;
using Action = hs_profile_Profile_Layer_Action;

NSController::NSController(std::unique_ptr<Teensy> teensy,
                           std::unique_ptr<NSPad> nspad)
    : teensy_(std::move(teensy)),
      nspad_(std::move(nspad)),
      base_mapping_({}),
      mod_mapping_({}) {
  // DPad direction with neutral SOCD. Bit order: Up, Down, Left, Right
  dpad_direction_[0] = nspad_->DPadCentered();   // 0000 None
  dpad_direction_[1] = nspad_->DPadRight();      // 0001
  dpad_direction_[2] = nspad_->DPadLeft();       // 0010
  dpad_direction_[3] = nspad_->DPadCentered();   // 0011 Left + Right cancel
  dpad_direction_[4] = nspad_->DPadDown();       // 0100
  dpad_direction_[5] = nspad_->DPadDownRight();  // 0101
  dpad_direction_[6] = nspad_->DPadDownLeft();   // 0110
  dpad_direction_[7] = nspad_->DPadDown();       // 0111 Left + Right cancel
  dpad_direction_[8] = nspad_->DPadUp();         // 1000
  dpad_direction_[9] = nspad_->DPadUpRight();    // 1001
  dpad_direction_[10] = nspad_->DPadUpLeft();    // 1010
  dpad_direction_[11] = nspad_->DPadUp();        // 1011 Left + Right cancel
  dpad_direction_[12] = nspad_->DPadCentered();  // 1100 Up + Down cancel
  dpad_direction_[13] = nspad_->DPadRight();     // 1101 Up + Down cancel
  dpad_direction_[14] = nspad_->DPadLeft();      // 1110 Up + Down cancel
  dpad_direction_[15] =
      nspad_->DPadCentered();  // 1111 Up + Down cancel; Left + Right cancel

  LoadProfile();
}

NSButtonPinMapping NSController::GetButtonPinMapping(const Layer& layer) {
  NSButtonPinMapping mapping;

  std::vector<pins::ActionPin> action_pins = pins::GetActionPins(layer);

  std::unordered_map<int, int> action_to_button_id = {
      {hs_profile_Profile_Layer_DigitalAction_X, 1},
      {hs_profile_Profile_Layer_DigitalAction_CIRCLE, 2},
      {hs_profile_Profile_Layer_DigitalAction_TRIANGLE, 3},
      {hs_profile_Profile_Layer_DigitalAction_SQUARE, 0},
      {hs_profile_Profile_Layer_DigitalAction_L1, 4},
      {hs_profile_Profile_Layer_DigitalAction_L2, 6},
      {hs_profile_Profile_Layer_DigitalAction_L3, 10},
      {hs_profile_Profile_Layer_DigitalAction_R1, 5},
      {hs_profile_Profile_Layer_DigitalAction_R2, 7},
      {hs_profile_Profile_Layer_DigitalAction_R3, 11},
      {hs_profile_Profile_Layer_DigitalAction_OPTIONS, 9},
      {hs_profile_Profile_Layer_DigitalAction_SHARE, 8},
      {hs_profile_Profile_Layer_DigitalAction_HOME, 12},
      {hs_profile_Profile_Layer_DigitalAction_CAPTURE, 13},
  };

  for (const auto& action_pin : action_pins) {
    auto action = action_pin.action;
    int pin = action_pin.pin;
    if (action.which_action_type ==
        hs_profile_Profile_Layer_Action_digital_tag) {
      auto digital = action.action_type.digital;
      if (action_to_button_id.find(digital) != action_to_button_id.end()) {
        int button_id = action_to_button_id[digital];
        if (mapping.button_id_to_pins.find(button_id) !=
            mapping.button_id_to_pins.end()) {
          mapping.button_id_to_pins[button_id].push_back(pin);
        } else {
          mapping.button_id_to_pins[button_id] = {pin};
        }
      } else {
        switch (digital) {
          case hs_profile_Profile_Layer_DigitalAction_R_STICK_UP:
            mapping.z_y.push_back({joystick_->get_max(), pin});
            break;
          case hs_profile_Profile_Layer_DigitalAction_R_STICK_DOWN:
            mapping.z_y.push_back({joystick_->get_min(), pin});
            break;
          case hs_profile_Profile_Layer_DigitalAction_R_STICK_LEFT:
            mapping.z_x.push_back({joystick_->get_min(), pin});
            break;
          case hs_profile_Profile_Layer_DigitalAction_R_STICK_RIGHT:
            mapping.z_x.push_back({joystick_->get_max(), pin});
            break;
          case hs_profile_Profile_Layer_DigitalAction_D_PAD_UP:
            mapping.dpad_up.push_back(pin);
            break;
          case hs_profile_Profile_Layer_DigitalAction_D_PAD_DOWN:
            mapping.dpad_down.push_back(pin);
            break;
          case hs_profile_Profile_Layer_DigitalAction_D_PAD_LEFT:
            mapping.dpad_left.push_back(pin);
            break;
          case hs_profile_Profile_Layer_DigitalAction_D_PAD_RIGHT:
            mapping.dpad_right.push_back(pin);
            break;
          case hs_profile_Profile_Layer_DigitalAction_MOD:
            mapping.mod.push_back(pin);
            break;
          default:
            break;
        }
      }
    } else {
      auto analog = action.action_type.analog;
      int value = analog.value;
      switch (analog.id) {
        case hs_profile_Profile_Layer_AnalogAction_ID_R_STICK_X:
          mapping.z_x.push_back({value, pin});
          break;
        case hs_profile_Profile_Layer_AnalogAction_ID_R_STICK_Y:
          mapping.z_y.push_back({value, pin});
          break;
        default:
          break;
      }
    }
  }

  return mapping;
}

void NSController::LoadProfile() {
  Layout layout = FetchProfile(*teensy_, hs_profile_Profile_Platform_SWITCH);
  joystick_ = std::make_unique<HallJoystick>(*teensy_, 0, 255,
                                             layout.joystick_threshold);
  base_mapping_ = GetButtonPinMapping(layout.base);
  if (layout.has_mod) {
    mod_mapping_ = GetButtonPinMapping(layout.mod);
  }
}

int NSController::GetDPadDirection(const NSButtonPinMapping& mapping) {
  int bits = 0;
  for (const int pin : mapping.dpad_up) {
    if (teensy_->DigitalReadLow(pin)) {
      bits |= 8;  // 1000
      break;
    }
  }
  for (const int pin : mapping.dpad_down) {
    if (teensy_->DigitalReadLow(pin)) {
      bits |= 4;  // 0100
      break;
    }
  }
  for (const int pin : mapping.dpad_left) {
    if (teensy_->DigitalReadLow(pin)) {
      bits |= 2;  // 0010
      break;
    }
  }
  for (const int pin : mapping.dpad_right) {
    if (teensy_->DigitalReadLow(pin)) {
      bits |= 1;  // 0001
      break;
    }
  }
  return dpad_direction_[bits];
}

void NSController::UpdateButtons(const NSButtonPinMapping& mapping) {
  nspad_->SetRightYAxis(
      joystick_->get_max() -
      ResolveSOCD(*teensy_, mapping.z_y, joystick_->get_neutral()));
  nspad_->SetRightXAxis(
      ResolveSOCD(*teensy_, mapping.z_x, joystick_->get_neutral()));

  for (const auto& element : mapping.button_id_to_pins) {
    for (const auto& pin : element.second) {
      if (teensy_->DigitalReadLow(pin)) {
        nspad_->Press(element.first);
        break;
      }
    }
  }

  nspad_->SetDPad(GetDPadDirection(mapping));
}
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

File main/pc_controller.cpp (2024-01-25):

// Copyright 2024 Hiram Silvey

#include "pc_controller.h"

#include <memory>

#include "controller.h"
#include "hall_joystick.h"
#include "pins.h"
#include "profile.pb.h"
#include "teensy.h"

namespace hs {

using Layout = hs_profile_Profile_Layout;
using Layer = hs_profile_Profile_Layer;
using Action = hs_profile_Profile_Layer_Action;

// DPad degrees with neutral SOCD.
const int kDPadAngle[16] = {
    // Bit order: Up, Down, Left, Right
    -1,   // 0000 None
    90,   // 0001 Right
    270,  // 0010 Left
    -1,   // 0011 Left + Right cancel
    180,  // 0100 Down
    135,  // 0101 Down + Right
    225,  // 0110 Down + Left
    180,  // 0111 Down; Left + Right cancel
    0,    // 1000 Up
    45,   // 1001 Up + Right
    315,  // 1010 Up + Left
    0,    // 1011 Up; Left + Right cancel
    -1,   // 1100 Up + Down cancel
    90,   // 1101 Right; Up + Down cancel
    270,  // 1110 Left; Up + Down cancel
    -1,   // 1111 Up + Down cancel; Left + Right cancel
};

PCController::PCController(std::unique_ptr<Teensy> teensy)
    : teensy_(std::move(teensy)), base_mapping_({}), mod_mapping_({}) {
  LoadProfile();
  teensy_->JoystickUseManualSend();
}

PCButtonPinMapping PCController::GetButtonPinMapping(const Layer& layer) {
  PCButtonPinMapping mapping;

  std::vector<pins::ActionPin> action_pins = pins::GetActionPins(layer);

  std::unordered_map<int, int> action_to_button_id = {
      {hs_profile_Profile_Layer_DigitalAction_X, 2},
      {hs_profile_Profile_Layer_DigitalAction_CIRCLE, 3},
      {hs_profile_Profile_Layer_DigitalAction_TRIANGLE, 4},
      {hs_profile_Profile_Layer_DigitalAction_SQUARE, 1},
      {hs_profile_Profile_Layer_DigitalAction_L1, 5},
      {hs_profile_Profile_Layer_DigitalAction_L2, 7},
      {hs_profile_Profile_Layer_DigitalAction_L3, 11},
      {hs_profile_Profile_Layer_DigitalAction_R1, 6},
      {hs_profile_Profile_Layer_DigitalAction_R2, 8},
      {hs_profile_Profile_Layer_DigitalAction_R3, 12},
      {hs_profile_Profile_Layer_DigitalAction_OPTIONS, 10},
      {hs_profile_Profile_Layer_DigitalAction_SHARE, 9}};
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

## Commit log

2021-04-24 Renamed joystick files and class to avoid collision with built-in Teensy USB class.
    [usb_controller.cc]
2021-04-25 Removed NGC controller implementation since it relies on AVR CPU assembly, and Teensy 4.0 has a Cortex-M7 CPU. I plan to write support for NGC in the future after USB is confirmed working. This versi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
2021-04-27 Fixed usb activation to be based on whether the USB is active rather than whether Serial is active. The usb_configuration variable is defined in the Teensy core libraries and used by the Teensy Joyst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
2021-04-29 Added basic implementation to fetch joystick axis values. Still need to define the input axis boundaries, likely with a calibration that stores the boundaries in EEPROM.
2021-05-01 Added basic calibration code for joystick. Fleshed out basic joystick code and verified it works, though there are still some kinks. Not yet fully playable.
2021-05-05 Wrote new rough calibration code that still needs a thorough cleaning. Switched from FASTMODE to LOWPOWERMODE for more precise readings. 1st prototype now appears to be fully functional.
2021-05-07 Added support for SSBM light shield button press, cleaned up some unnecessary code. Next step is to separate game specific code into profiles which can be written to and loaded from EEPROM.
2021-05-08 Added initial code to read serial data from the client configurator. This is currently broken and does not compile, though.
    [main.ino, main.rs]
2021-05-08 Fixed compile error due to missing Arduino.h header.
    [main.ino]
2021-05-08 Add delay to profile loading code to ensure button states are settled before relying on them. That delay will eventually be moved to a better location, but is OK for now.
2021-05-09 Removed TODOs and opened issues tracking their progress.
    [calibrate.ino, profiles.cpp]
2021-05-12 Started setting up configurator to create profile objects, manipulate them, and write them to EEPROM. Current code in main.rs is scratch and will largely be replaced.
    [main.rs]
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2021-05-29 Refactored encode functions into new module, manually tested and partially verified. Currently the smallest profile is 15 bytes. This is not maximum compression, but it should be fine for the time be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
2021-05-30 Moved delay ensuring pin state stability out of controller-code into main so it applies to all starting button states.
    [main.ino, profiles.cpp]
2021-05-31 Refactored encoder library to properly propagate errors from the correct sources.
2021-06-19 Fixed compilation errors and started debugging with print statements. :P
    [profiles.cpp]
2021-06-21 Fixed getting stuck in profiles store loop by moving delay from main to pin init fn.
    [main.ino, profiles.cpp]
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2021-06-27 Added physical support files.
    [magnet_harness.scad, magnet_harness_05_spacing.stl, sensor_harness.scad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]
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2021-07-04 Functional on switch with some caveats. Fixed inverse R stick Y axis.
    Switch requires masquerading as a supported controller type, unfortunately. This means that the Teensy can no longer be identified as a Teensy board to work on the Switch. The current idea is to have the Teensy identify itself as both a Switch-compatible controller and as a PC Joystick. However, this means that PCs actually detect 2 controllers being connected, though only the Joystick interface actually communicates with the PC, as the other interface is specifically for the Switch protocol. It may be possible to switch the VID/PID of the board dynamically, but I haven't yet figured out a way to do that. Still investigati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
    [ns_controller.cpp]
2021-07-06 Enabled loading Switch joystick interface when holding down a button to start. A composite USB type of PC Joystick and NS Gamepad is still needed for now, meaning uploading new code to the Teensy sti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
    [main.ino, ns_controller.cpp, pc_controller.cpp]
2021-07-10 Lost decimal point of joystick precision to prevent 32 bit integer overflow when mapping to a smaller integer range.
    [calibrate.ino, main.ino]
2021-07-10 Moved pin initialization to usb.c cores file. First working version that allows selecting USB type at power on.
2021-07-14 Refactored calibration / configuration code into a single class that can be called into by main.
2021-07-14 Re-organized directory structure.
    [magnet_harness.scad, magnet_harness_05_spacing.stl, sensor_harness.scad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]
2021-07-17 Integrated configurator with a VERY basic UI! Restored original joystick precision, and fixed joystick calibration to enable full values in any direction without pressing harder than what is expected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
    [main.rs]
2021-07-18 Added missing copyright comments.
    [main.rs]
2021-07-24 Added Guilty Gear -strive- layout and fixed layout loading controller code typo.
    [main.rs]
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2021-07-29 If no action is mapped to a button, automatically map it to NO_OP. Updated GGST profile to use the digital joystick functionality and manually tested with success.
2021-08-02 Early unfinished draft of new calibration methodology. GUI will be heavily involved.
2021-08-07 New button layouts for standardized AFS 14, 16, and 18in universal bodies. Untested. #8
2021-08-07 Updated joystick calibration UI to properly map between the joystick sensor outputs and the druid display points.
2021-08-08 Able to fetch bounds and read live joystick data in the configurator. Need to spawn a separate thread to display that data in the UI though.
2021-08-10 Initial draft with separate data fetching and UI threads. Not finished. Needs refactoring.
2021-08-11 Full calibration overhaul draft complete. All code compiles, but is completely untested. Likely has bugs.
    [main.ino, main.rs]
2021-08-12 First working version of new calibration method. Needs a lot of polishing, but a basic functioning idea now exists!
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2021-08-20 Updated panel SVGs to play nicer with laser cutting services, where dimensions are properly described in mm in the svg now.
2021-09-19 Updated encoder to additionally encode mod layer. Doubles the size of the encoded bytes, with a size increase from ~10B to ~20B. This is OK for now, but may be optimized in a future patch.
2021-09-30 Updated proto to make the configuration more straightforward and to simplify the changes needed in the controller code. Updated decoder to match. Encoder still needs to be updated.
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2021-10-02 Updated text profiles to utilize new proto. Updated configurator printing code and verified profiles are read correctly.
    [main.rs]
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2021-12-10 Reordered profiles. Note that profile #2 currently doesn't work likely due to a hardware bug.
2021-12-14 Separated out some of the button pin mapping struct into the general controller class.
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2021-12-21 Moved test files into dedicated test directory. Fixed teensyduino compile errors.
    [ns_controller.cpp, pc_controller.cpp]
2021-12-23 Refactoring to use CMake for tests instead of Bazel. Currently does not build.
2021-12-23 Major refactoring to mock out nsgamepad hardware dependencies. Compiles on arduino IDE.
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2021-12-23 Renamed mcu -> teensy. Ran clang-format over all files using google style.
2021-12-24 Overhauled CMakeLists.txt. Single test currently compiles but fails to link.
    [ns_controller.cpp, pc_controller.cpp]
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2021-12-29 Added hall joystick tests, fixed bug in normalizing the value.
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2022-01-03 Updated ssbm profile to allow for easier access to the Z button.
2022-01-03 Removed buttons that won't be present on the v1.0 build.
    [controller_test.cpp, main.ino]
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2022-01-04 Fixed mod layer decoding issue. A byte was accidentally being skipped while decoding when the base layer's last button didn't leave any additional bits to read on its byte.
    [main.rs]
2022-01-07 Updated sensor harness to utilize screw hole.
    [sensor_harness.scad, sensor_harness_01_spacing.stl]
2022-01-09 Updated ssbm profile, duplicating L-cancel (lightshield) button onto two rows to ease finger stretching requirements.
2022-01-09 Set joystick sensor to MASTERCONTROLLEDMODE to improve joystick jitter (read: accuracy) as we only need to update the joystick coordinate as fast as the teensy can poll for it.
2022-01-10 Prevent fetching joystick sensor data too quickly, as that can result in unpredictable results.
2022-01-12 Updated magnet harness to ensure min wall thickness is actually 1mm.
    [magnet_harness.scad]
2022-02-02 Added basic support for axes rotation correction.
    [main.rs]
2022-02-02 Finalized magnet harness spacing when ordering through ShapeWays.
    [magnet_harness.scad]
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2022-02-02 Controller side rotation implementation. Joystick test currently fails, needs debugging.
2022-02-03 Fixed misunderstanding in rotation.
    [main.rs]
2022-02-03 Removed obsolete model.
    [magnet_harness_05_spacing.stl]
2022-02-09 Updated STL files and verified they work when ordering from ShapeWays.
    [magnet_harness.stl, sensor_harness.scad, sensor_harness.stl]
2022-02-24 Added core panel layout options with the 3 bottom right buttons removed.
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2022-10-18 Pins used to determine profiles and configurator mode weren't pulled up and given the proper time to stabilize. Added an explicit InitPins function to ensure pin readings at startup are as consistent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
    [main.ino]
2022-10-20 Testing new JLF mods.
    [magnet_harness.scad, magnet_harness.stl, sensor_harness.scad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]
2022-10-21 Updated magnet harness.
    [magnet_harness.scad]
2022-10-21 Added spacing variable to sensor harness.
    [sensor_harness.scad]
2022-10-28 Updated spacing based on the successful Prusa i3 prints.
    [magnet_harness.scad, sensor_harness.scad]
2022-10-28 Updated magnet size.
    [magnet_harness.scad, sensor_harness.scad]
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2024-01-25 Updated copyright. Added trunk.io formatters.
    [.isort.cfg]
